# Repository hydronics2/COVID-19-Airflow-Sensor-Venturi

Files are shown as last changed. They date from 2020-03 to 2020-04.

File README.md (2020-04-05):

#### This sensor was abandoned because it was similar enough to another prototype using venturi type sensor based on a delta pressure reading. An ongoing airflow sensor project is here: [AFH55M12](https://github.com/hydronics2/COVID-19-Airflow-Sensor-AFH55M12) 

# Easy Flow Rate Sensor - venturi PCB

## Project Description ([from Helpful Engineering](https://www.helpfulengineering.org/))
The intent here is to create a monitoring device, based on a mass airflow meter, that can be used when splitting a ventilator into two or more patients. This will allow staff to monitor individual patients while being controlled by one device in extreme situations where the number of ventilators are not enough to handle the number of patients. The readout should be visible locally on the device and there may need to be parameters input by staff to create a safe operating range and to possibly create alarms when the system is measuring an out of range parameter.

### [Project Requirements](https://docs.google.com/document/d/17Ps910A2vRwnM4EM6F-71GNG1XNa0PaeImd53F7428c/edit?usp=sharing)

This version of the flow rate sensor PCB has off the shelf micro-controllers for quick prototyping. Developed through

The printed circuit board (PCB) accepts multiple Arduino platforms made by Adafruit including their line of [Adafruit Feather](https://www.adafruit.com/category/777) type micro-controllers and [Adafruit ItsyBitsy](https://www.adafruit.com/category/1008) micro-controllers.   The Adafruit feathers include wifi and SAMD M0 and M4 options. All the ItsyBitsy 3V models (M0, M4, and 32u4) should work fine.

[google Doc](https://docs.google.com/document/d/14zgp7OhsyWClFdLCb04ITVAHAoAawH8Gl29P4oe5PJs/edit?usp=sharing)

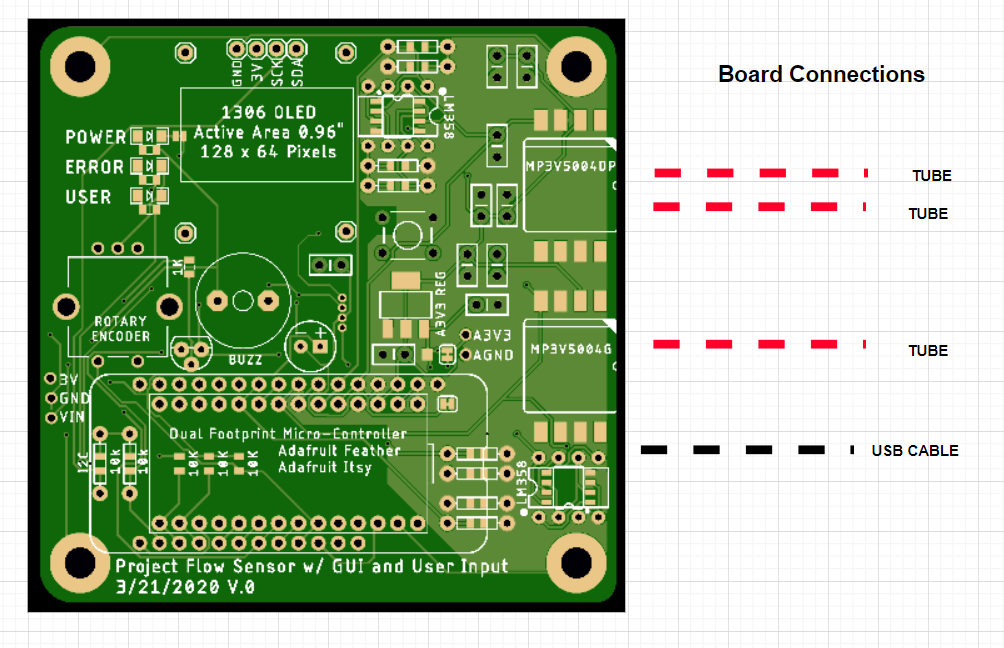
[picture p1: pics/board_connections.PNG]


### Still to do
- select the operational amplifiers and gain serving the pressure sensors
- Select alarm conditions
- Might need to add a separate power connector (⅛” barrel?)  as the USB micro connector might not be strong enough
- Verify any i2C conflicts between humidity sensor and OLED display

### General Operation
.....

### Bill of Materials
- differential pressure sensor, MP3V5004DP,
- gauge pressure sensor, MP3V5004G
- humidity sensor through-hole - H1H800, digikey 480-5706-1-ND
- humidity sensor surface mount - SHTC3, digikey 1649-1100-1-ND
- piezo buzzer, generic, 6.5mm pitch
- transistor to drive piezo pn2222A
- oled display, generic 1306 OLED, 128 x 64 pixels
- Linear 3.3v regulator LDL1117S33R
- Rotary Encoder and momentary switch, Bourns PEC12R-4220F-S0012-ND
- generic 6mm user defined momentary tactile switch
- generic 1206 smd LEDs for Power, Error, and TBD LED indicator

### Pressure Sensors
Two pressure sensors used here. Both manufactured by [NXP MP3V5004 Series](https://www.nxp.com/docs/en/data-sheet/MP3V5004G.pdf)
- One pressure sensor measures differential pressure from an external venturi
- One pressure sensor measures gauge pressure.
Both pressure sensors are connected directly to the micro-controllers ADC inputs as well as operational amplifiers so their outputs may be amplified as needed. (A0, A1, A2, A3,A4,A5).
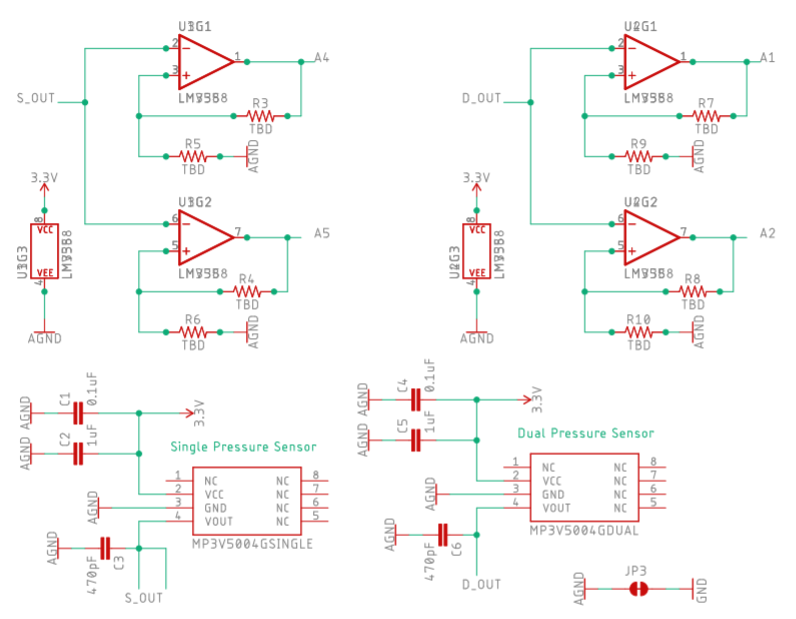
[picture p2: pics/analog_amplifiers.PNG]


### Micro-Controller Pinout
#### Feather ESP32 Pinout
#### Not up to date
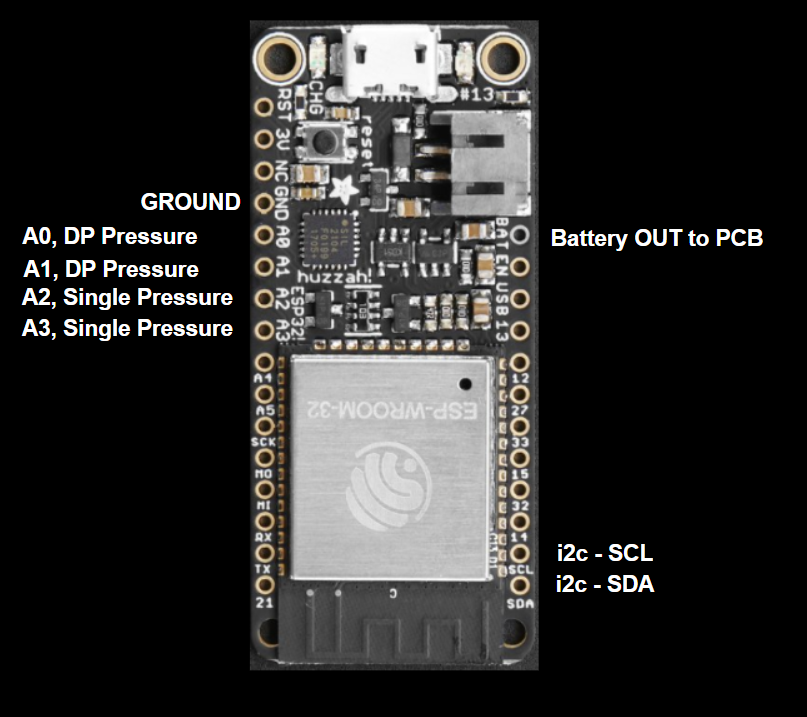
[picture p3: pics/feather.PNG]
feather

#### ItsyBitsy Pinout
#### Not up to date
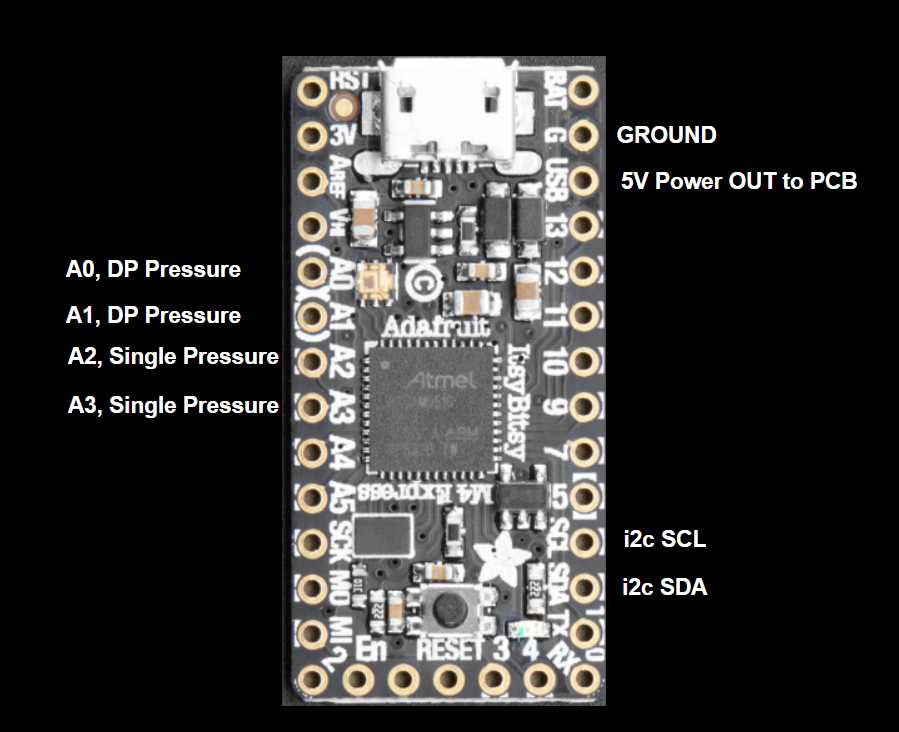
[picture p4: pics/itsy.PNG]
itsy


### Power
Power is delivered through the USB cable on the micro-controller. The Feather micro-controllers have a lipo charge circuit.  The main board is powered from the vBat pin of the micro-controller. The smaller Adafruit micro-controller does not have a lipo charge circuit and powers the PCB from the USB pin.
Feather lipo charge circuit. A 3.3v linear regulator is the analog power supply to the pressure sensors and operational amplifiers. This is a generic 3.3V regulator: LDL1117S33R
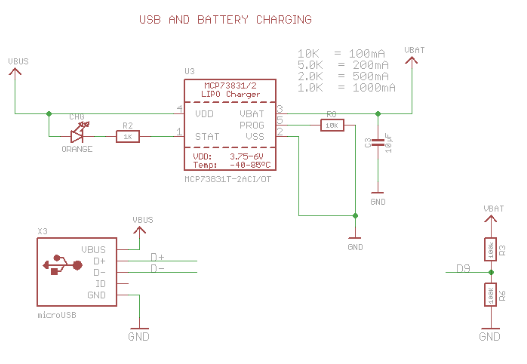
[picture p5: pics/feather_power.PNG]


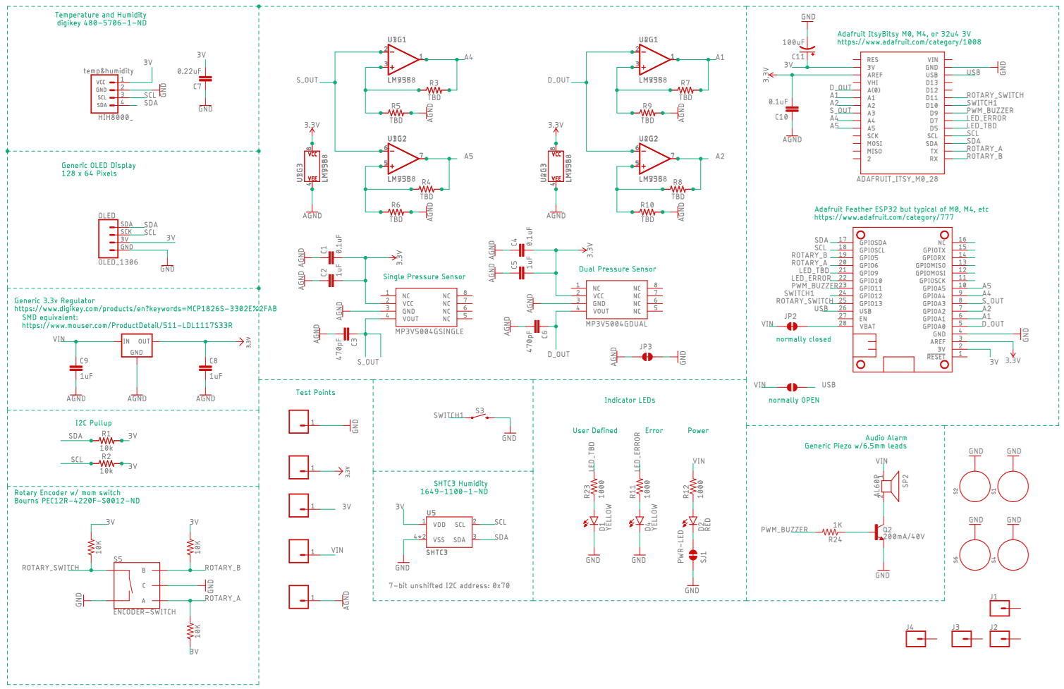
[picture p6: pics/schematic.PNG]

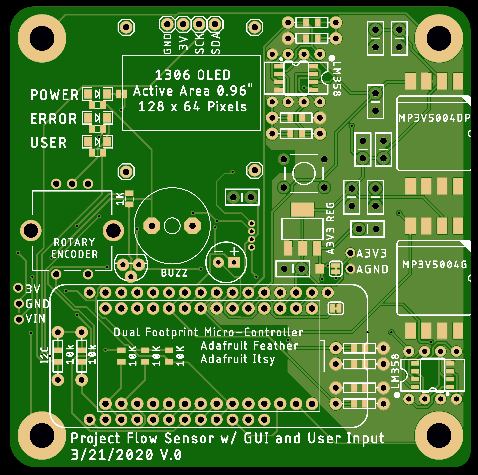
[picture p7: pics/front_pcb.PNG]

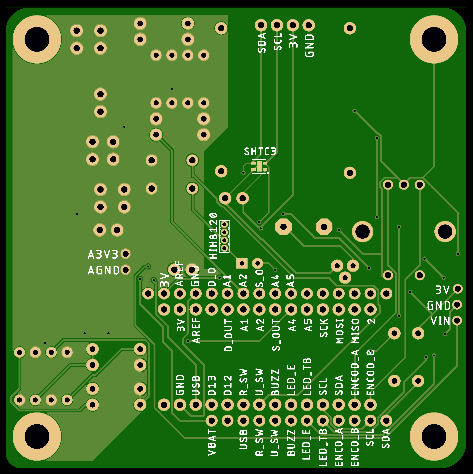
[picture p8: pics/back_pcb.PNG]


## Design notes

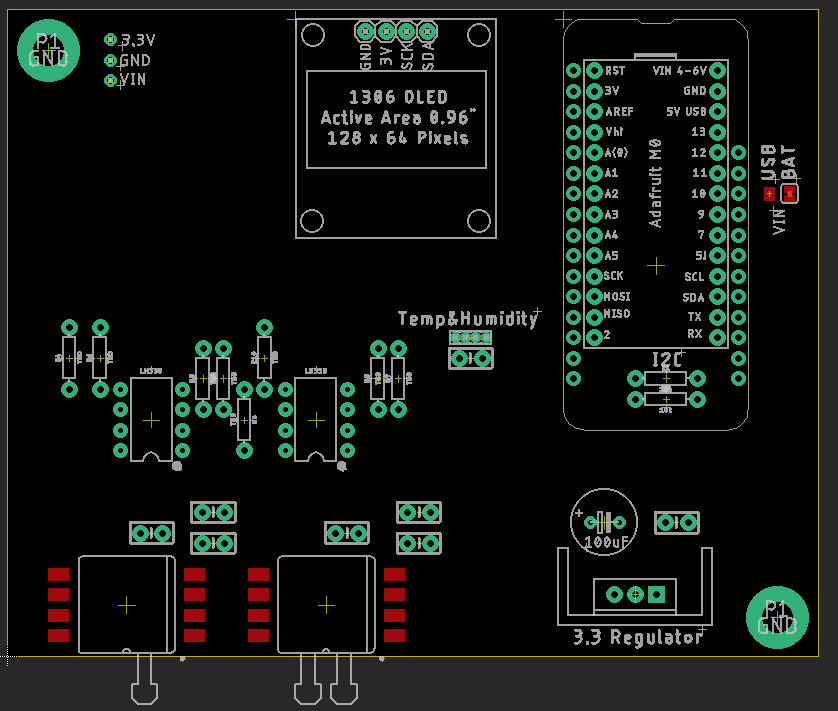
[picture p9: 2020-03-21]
pics/board view.PNG

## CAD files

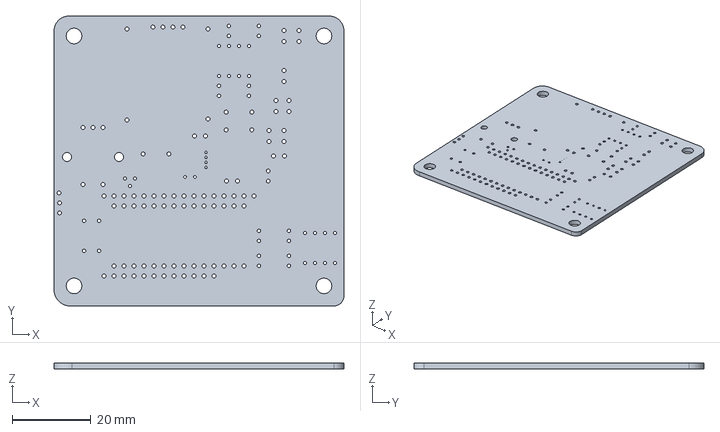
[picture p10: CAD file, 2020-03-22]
PCB files/kicad/air_flow.step
73.7 x 73.7 x 1.60 mm

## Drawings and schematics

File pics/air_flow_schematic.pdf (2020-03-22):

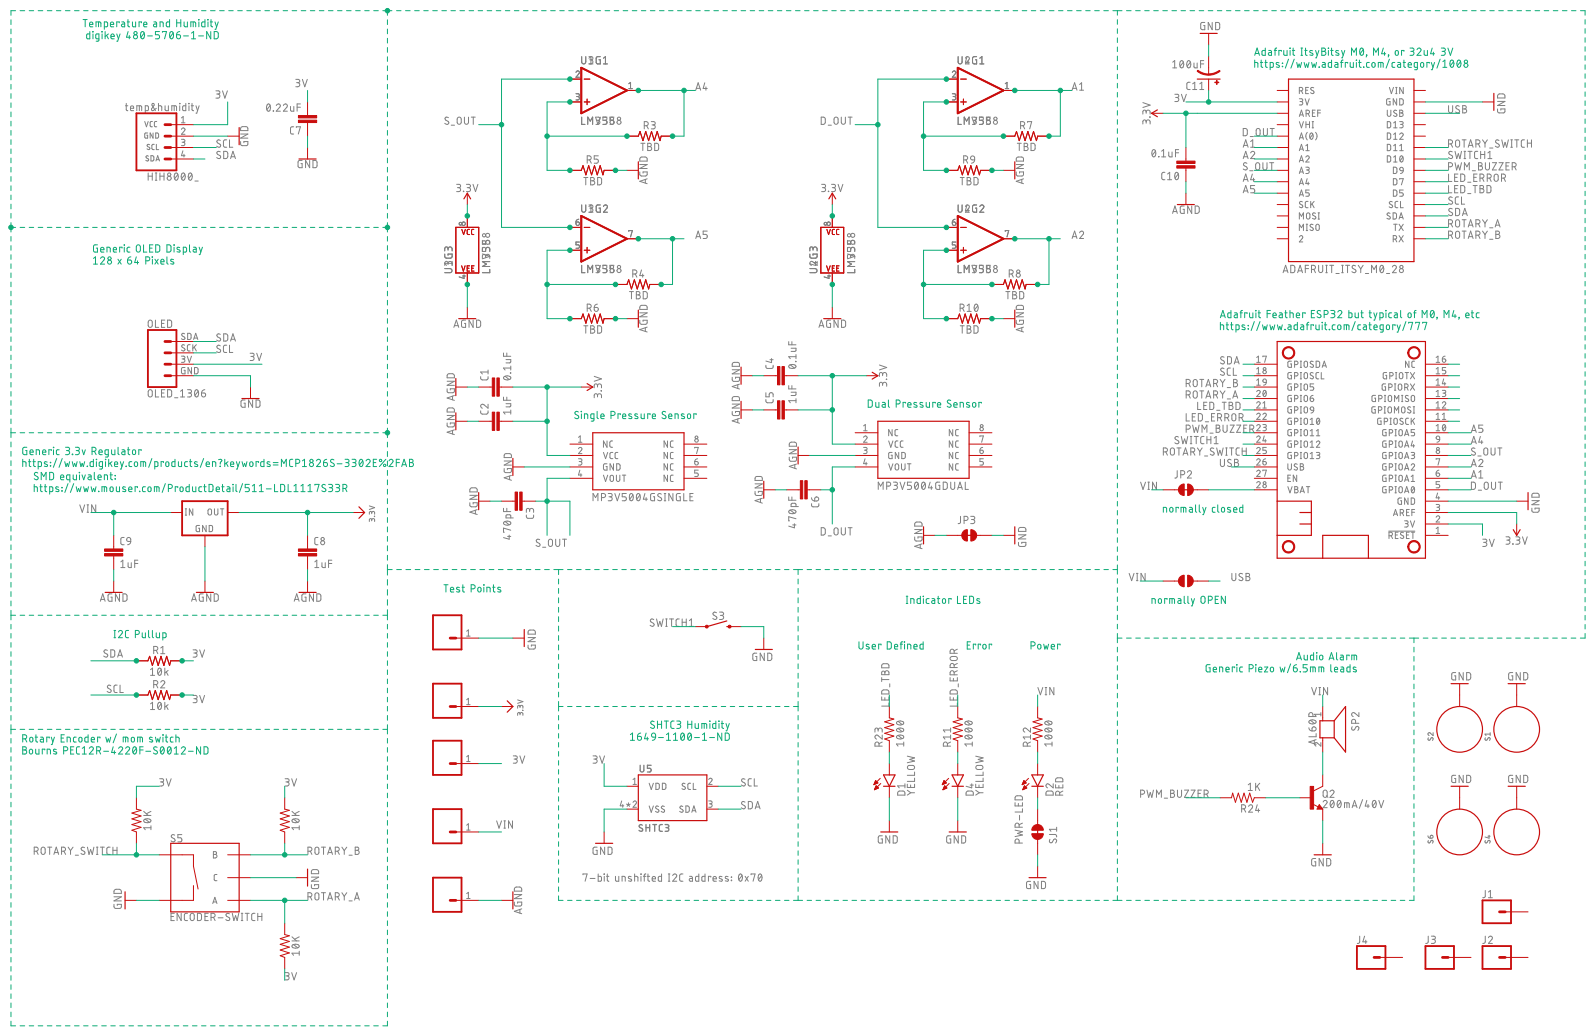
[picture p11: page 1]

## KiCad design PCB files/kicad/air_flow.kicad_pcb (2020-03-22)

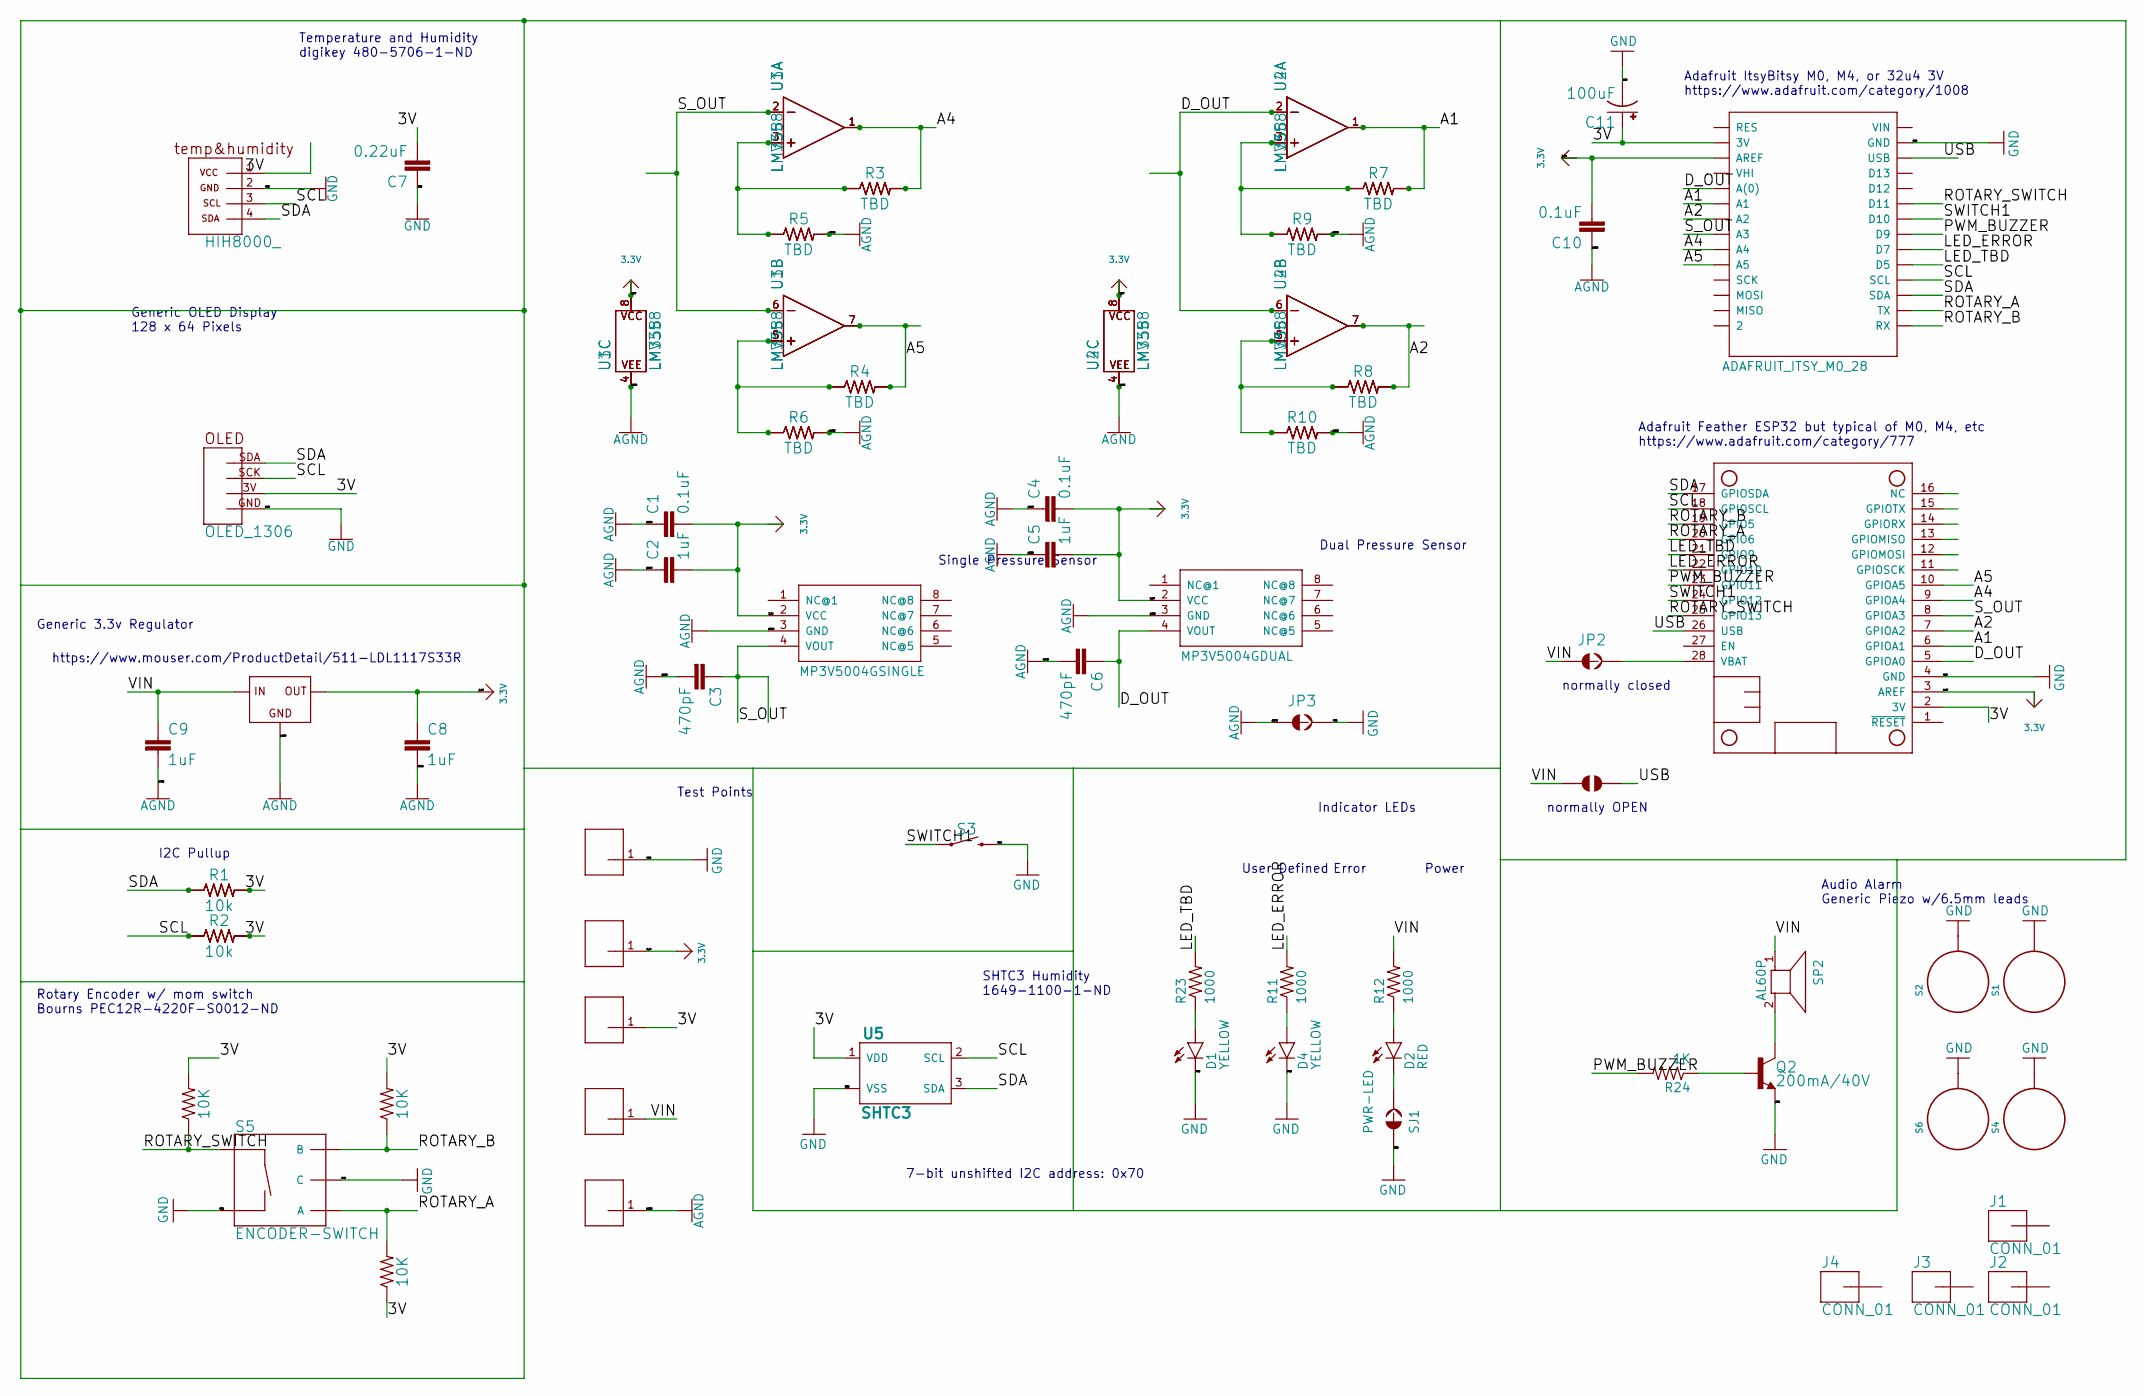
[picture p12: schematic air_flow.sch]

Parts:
3V_REGULATOR1: LDL1117_5V_REG; SOT223
C1, C4, C10: 0.1uF; CAP-PTH-SMALL-KIT
C2, C5, C8, C9: 1uF; CAP-PTH-SMALL-KIT
C3, C6: 470pF; CAP-PTH-SMALL-KIT
C7: 0.22uF; CAP-PTH-SMALL-KIT
C11: 100uF; CPOL-RADIAL-2.5MM-6.5MM
D1, D4: YELLOW; LED-1206
D2: RED; LED-1206
J1, J2, J3, J4: CONN_01; 1X01
JP1: JUMPER-SMT_2_NO_NO-SILK; SMT-JUMPER_2_NO_NO-SILK
JP2, JP3: JUMPER-SMT_2_NC_TRACE_SILK; SMT-JUMPER_2_NC_TRACE_SILK
MS2: FEATHERWING_NODIM; FEATHERWING_DIM
Q2: 200mA/40V; TO-92
R1, R2: 10k; AXIAL-0.3
R3, R4, R5, R6, R7, R8, R9, R10: TBD; AXIAL-0.3
R11, R12, R23: 1000; 0805
R13, R14, R15, R16, R17, R18, R19, R20, R21, R22: 0.3; 0805
R24: 1K; 0805
R26, R27, R28: 10K; 0805
S1, S2, S4, S6: STANDOFF_ELECTRICAL5-32; STANDOFF_ELECTRICAL_5_32
S3: MOMENTARY-SWITCH-SPST-PTH-6.0MM-KIT; TACTILE_SWITCH_PTH_6.0MM_KIT
S5: ENCODER-SWITCH; ROTARY_ENC_PLAIN
SJ1: PWR-LED; PAD-JUMPER-2-NC_BY_TRACE_NO_SILK
SP2: AL60P
U1, U2: LM358; DIP08
U3, U4: LMV358; SO08
U5: SHTC3
U$1: OLED_1306
U$2: MP3V5004GSINGLE; MP3V5004GP
U$3: MP3V5004GDUAL; MP3V5004DP
U$4: HIH8000_; HIH8120_TH
U$20, U$26, U$31, U$39, U$40: CONN_0138MILL; 1X01-40MILL
U$45: ADAFRUIT_ITSY_M0_28; ADAFRUIT_ITS_MO_28

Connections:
3.3V: 3V_REGULATOR1.2 (OUT), 3V_REGULATOR1.4 (OUT), C1.2, C2.2, C4.2, C5.2, C8.1, C10.2, MS2.3 (AREF), U1.8 (P$V+), U2.8 (P$V+), U3.8 (P$V+), U4.8 (P$V+), U$2.2 (VCC), U$3.2 (VCC), U$39.1, U$45.AREF
/3V: C7.2, C11.1 (+), MS2.2 (3V), R1.P$2 (2), R2.P$2 (2), R21.2, R22.2, R26.2, R27.1, R28.2, U5.1 (VDD), U$1.3V (VCC), U$4.1 (VCC), U$20.1, U$45.3V
/A1: MS2.6 (GPIOA1), R7.P$2 (2), R17.2, U2.1 (OUT), U4.1 (OUT), U$45.A1
/A2: MS2.7 (GPIOA2), R8.P$2 (2), R19.2, U2.7 (OUT), U4.7 (OUT), U$45.A2
/A4: MS2.9 (GPIOA4), R3.P$2 (2), R16.2, U1.1 (OUT), U3.1 (OUT), U$45.A4
/A5: MS2.10 (GPIOA5), R4.P$2 (2), R14.2, U1.7 (OUT), U3.7 (OUT), U$45.A5
/D_OUT: C6.1, MS2.5 (GPIOA0), U2.2 (-IN), U2.6 (-IN), U4.2 (-IN), U4.6 (-IN), U$3.4 (VOUT), U$45.A0 (A(0))
/LED_ERROR: MS2.22 (GPIO10), R11.2, U$45.D7
/LED_TBD: MS2.21 (GPIO9), R23.2, U$45.D5
/PWM_BUZZER: MS2.23 (GPIO11), R24.2, U$45.D9
/ROTARY_A: MS2.20 (GPIO6), R27.2, S5.A, U$45.TX
/ROTARY_B: MS2.19 (GPIO5), R26.1, S5.B, U$45.RX
/ROTARY_SWITCH: MS2.25 (GPIO13), R28.1, S5.SW+, U$45.D11
/SCL: MS2.18 (GPIOSCL), R2.P$1 (1), R22.1, U5.2 (SCL), U$1.SCK, U$4.3 (SCL), U$45.SCL
/SDA: MS2.17 (GPIOSDA), R1.P$1 (1), R21.1, U5.3 (SDA), U$1.SDA, U$4.4 (SDA), U$45.SDA
/SWITCH1: MS2.24 (GPIO12), S3.1, U$45.D10
/S_OUT: C3.1, MS2.8 (GPIOA3), U1.2 (-IN), U1.6 (-IN), U3.2 (-IN), U3.6 (-IN), U$2.4 (VOUT), U$45.A3
/USB: JP1.2, MS2.26 (USB), U$45.USB
/VIN: 3V_REGULATOR1.3 (IN), C9.1, JP1.1, JP2.1, R12.2, SP2.1, U$40.1
AGND: 3V_REGULATOR1.1 (GND), C1.1, C2.1, C3.2, C4.1, C5.1, C6.2, C8.2, C9.2, C10.1, JP3.1, R5.P$2 (2), R6.P$2 (2), R9.P$2 (2), R10.P$2 (2), R13.2, R15.2, R18.2, R20.2, U1.4 (P$V-), U2.4 (P$V-), U3.4 (P$V-), U4.4 (P$V-), U$2.3 (GND), U$3.3 (GND), U$26.1
GND: C7.1, C11.2 (-), D1.C, D4.C, JP3.2, MS2.4 (GND), Q2.1 (E), S1.P1, S2.P1, S3.3 (2), S4.P1, S5.C, S5.SW-, S6.P1, SJ1.1, U5.4 (VSS), U5.5 (VSS), U$1.GND, U$4.2 (GND), U$31.1, U$45.GND
unnamed: D1.A, R23.1
unnamed: D2.A, R12.1
unnamed: D2.C, SJ1.2
unnamed: D4.A, R11.1
unnamed: JP2.2, MS2.28 (VBAT)
unnamed: Q2.2 (B), R24.1
unnamed: Q2.3 (C), SP2.2
unnamed: R8.P$1 (1), R10.P$1 (1), R19.1, R20.1, U2.5 (+IN), U4.5 (+IN)
unnamed: R3.P$1 (1), R5.P$1 (1), R13.1, R16.1, U1.3 (+IN), U3.3 (+IN)
unnamed: R4.P$1 (1), R6.P$1 (1), R14.1, R15.1, U1.5 (+IN), U3.5 (+IN)
unnamed: R7.P$1 (1), R9.P$1 (1), R17.1, R18.1, U2.3 (+IN), U4.3 (+IN)

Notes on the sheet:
I2C Pullup
Dual Pressure Sensor
Single Pressure Sensor
Temperature and Humidity digikey 480-5706-1-ND
Generic OLED Display 128 x 64 Pixels
normally closed
normally OPEN
Adafruit ItsyBitsy M0, M4, or 32u4 3V https://www.adafruit.com/category/1008
Adafruit Feather ESP32 but typical of M0, M4, etc https://www.adafruit.com/category/777
Generic 3.3v Regulator
Test Points
Indicator LEDs
Power
Error
User Defined
https://www.mouser.com/ProductDetail/511-LDL1117S33R
Audio Alarm Generic Piezo w/6.5mm leads
Rotary Encoder w/ mom switch Bourns PEC12R-4220F-S0012-ND
7-bit unshifted I2C address: 0x70
SHTC3 Humidity 1649-1100-1-ND

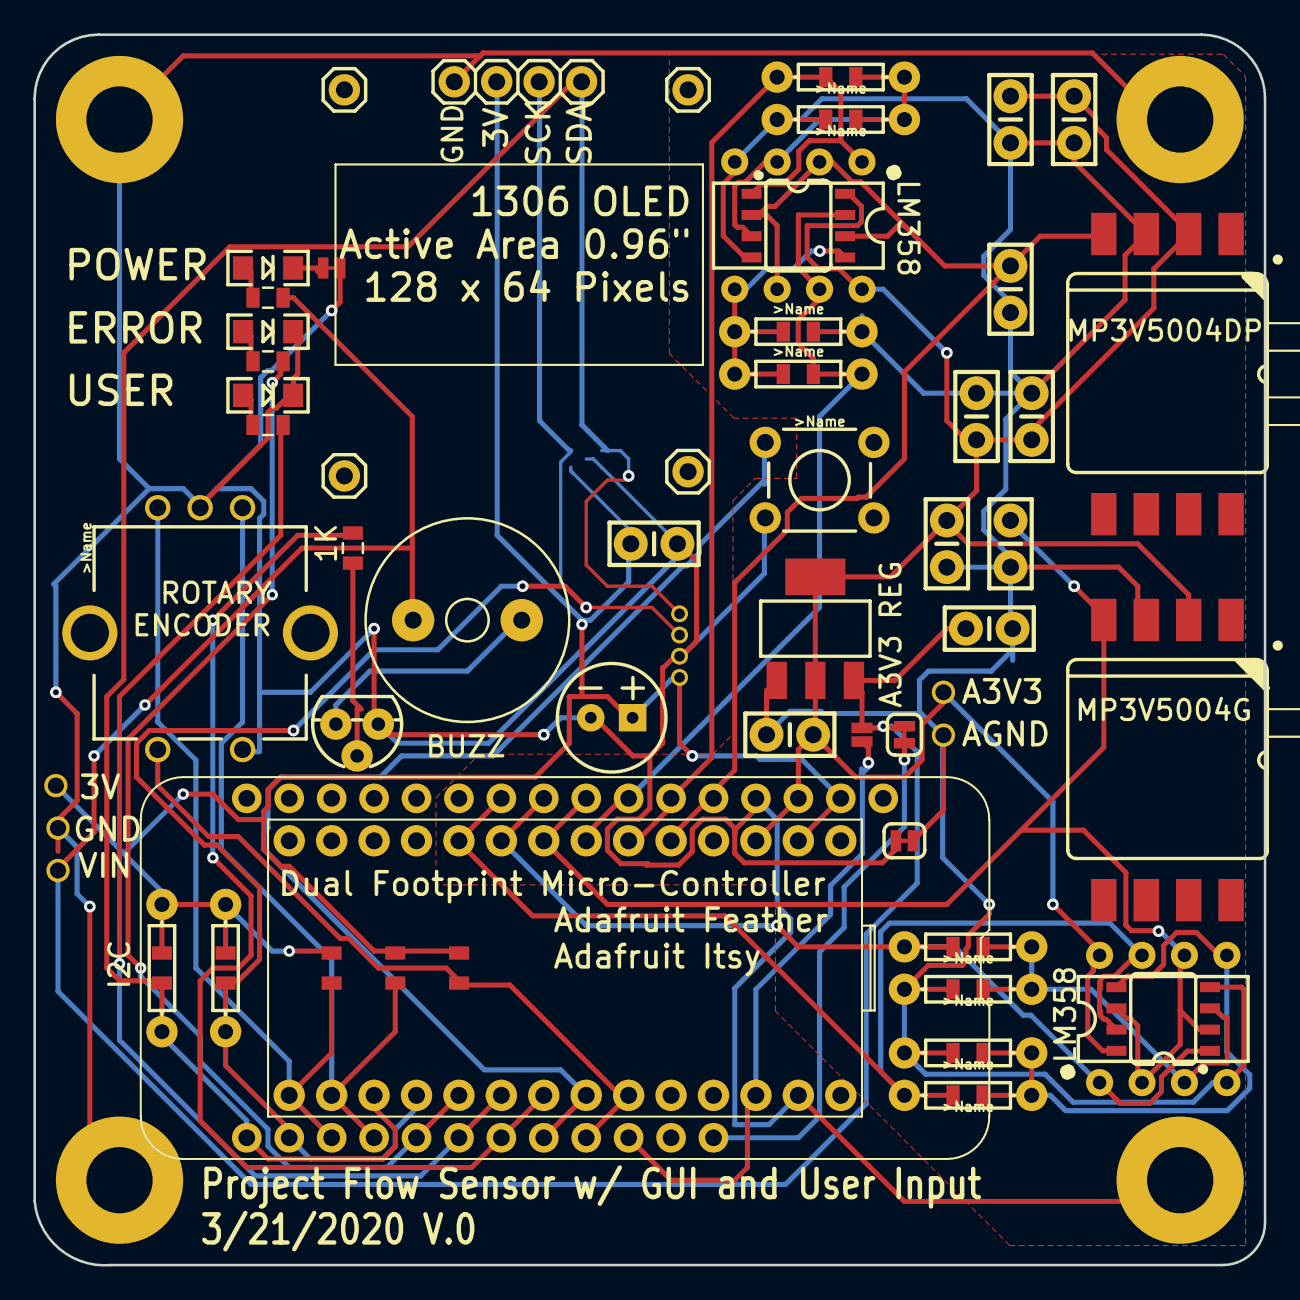
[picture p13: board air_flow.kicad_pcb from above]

Board: 2 copper layers, 73.7 x 73.7 mm, 74 parts (0 on the bottom side), 32 nets.

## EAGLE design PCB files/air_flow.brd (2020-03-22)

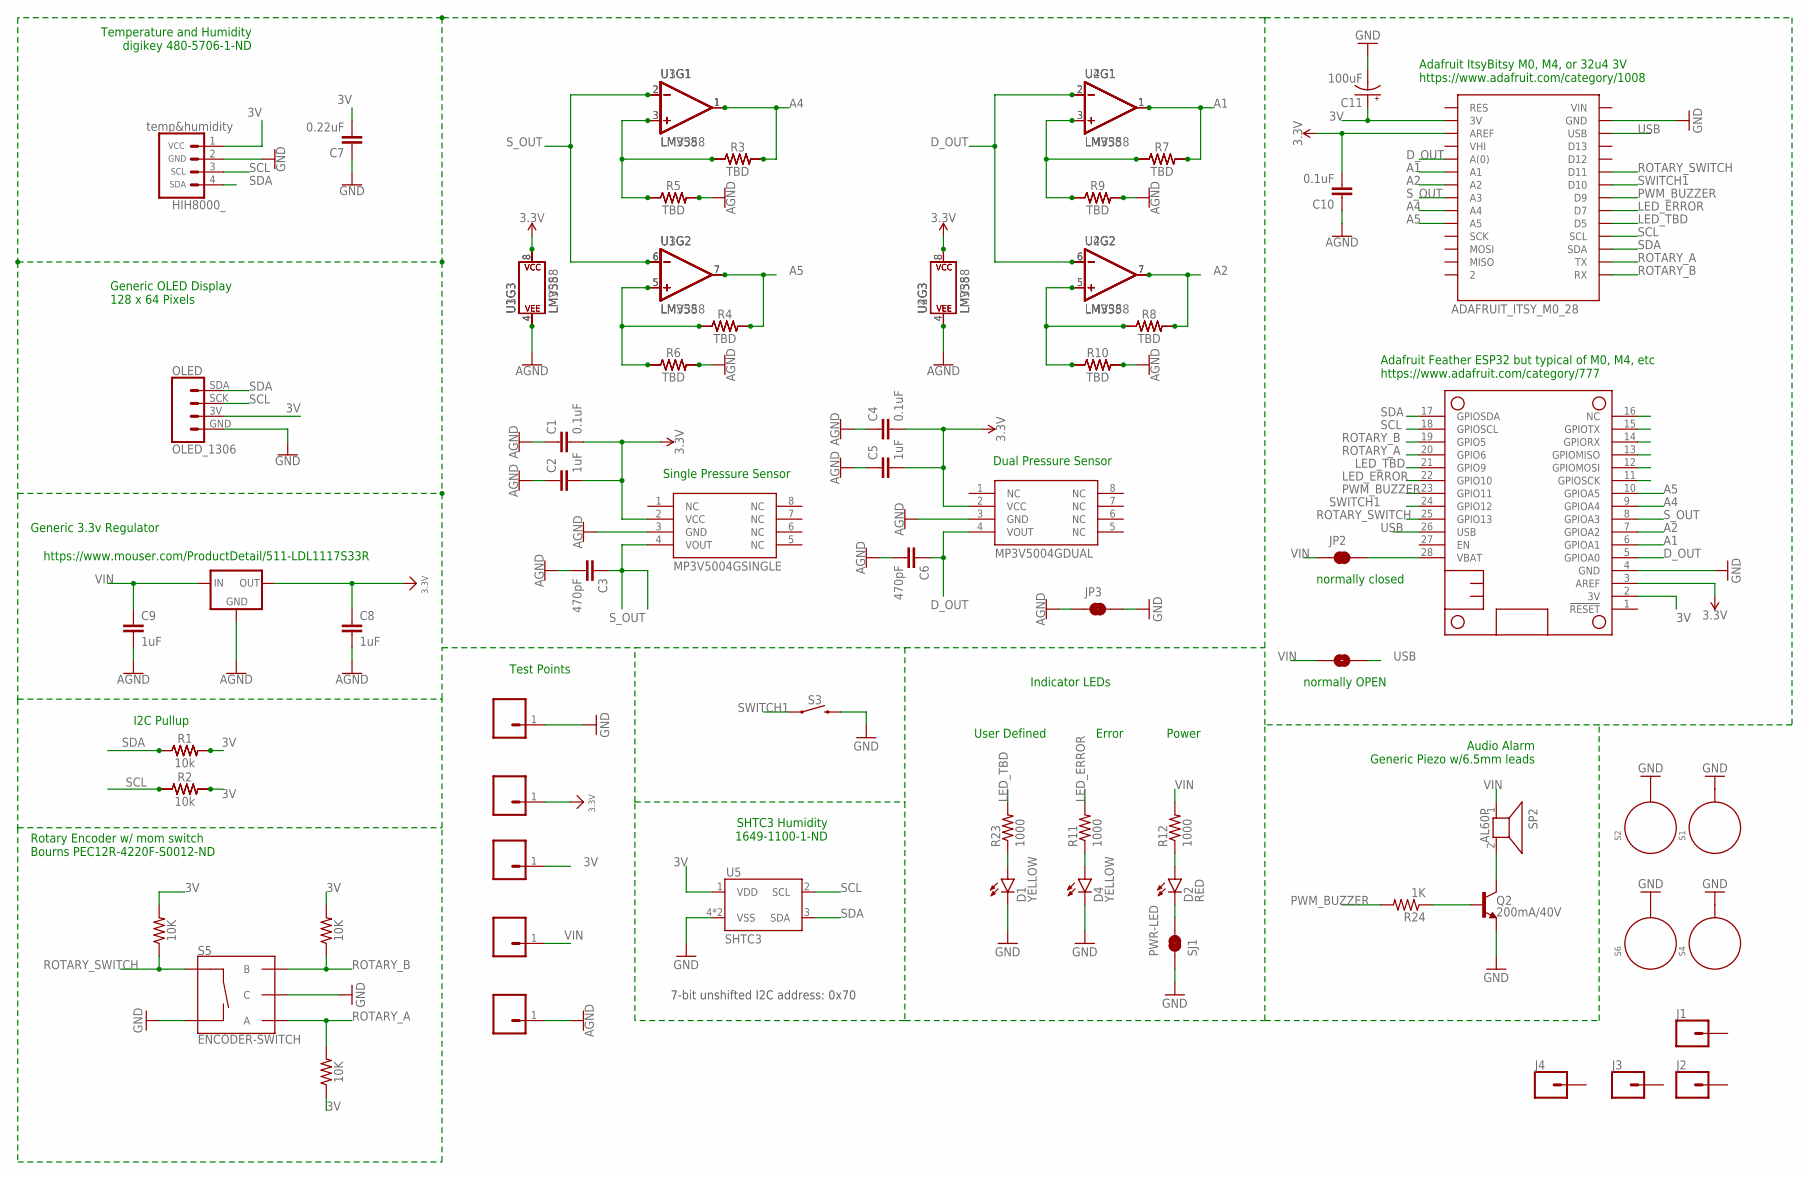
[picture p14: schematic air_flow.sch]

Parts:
3V_REGULATOR: LDL1117_5V_REG; SOT223
C1, C4, C10: 0.1uF; CAP-PTH-SMALL-KIT
C2, C5, C8, C9: 1uF; CAP-PTH-SMALL-KIT
C3, C6: 470pF; CAP-PTH-SMALL-KIT
C7: 0.22uF; CAP-PTH-SMALL-KIT
C11: 100uF; CPOL-RADIAL-2.5MM-6.5MM
D1, D4: YELLOW; LED-1206
D2: RED; LED-1206
J1, J2, J3, J4: CONN_01; 1X01
JP1: JUMPER-SMT_2_NO_NO-SILK; SMT-JUMPER_2_NO_NO-SILK
JP2, JP3: JUMPER-SMT_2_NC_TRACE_SILK; SMT-JUMPER_2_NC_TRACE_SILK
MS2: FEATHERWING_NODIM; FEATHERWING_DIM
Q2: 200mA/40V; TO-92
R1, R2: 10k; AXIAL-0.3
R3, R4, R5, R6, R7, R8, R9, R10: TBD; AXIAL-0.3
R11, R12, R23: 1000; 0805
R13, R14, R15, R16, R17, R18, R19, R20, R21, R22: 0.3; 0805
R24: 1K; 0805
R26, R27, R28: 10K; 0805
S1, S2, S4, S6: STANDOFF_ELECTRICAL5-32; STANDOFF_ELECTRICAL_5_32
S3: MOMENTARY-SWITCH-SPST-PTH-6.0MM-KIT; TACTILE_SWITCH_PTH_6.0MM_KIT
S5: ENCODER-SWITCH; ROTARY_ENC_PLAIN
SJ1: PWR-LED; PAD-JUMPER-2-NC_BY_TRACE_NO_SILK
SP2: AL60P
U1, U2: LM358; DIP08
U3, U4: LMV358; SO08
U5: SHTC3
U$1: OLED_1306
U$2: MP3V5004GSINGLE; MP3V5004GP
U$3: MP3V5004GDUAL; MP3V5004DP
U$4: HIH8000_; HIH8120_TH
U$20, U$26, U$31, U$39, U$40: CONN_0138MILL; 1X01-40MILL
U$45: ADAFRUIT_ITSY_M0_28; ADAFRUIT_ITS_MO_28

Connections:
3.3V: 3V_REGULATOR.2 (OUT), 3V_REGULATOR.4 (OUT), C1.2, C2.2, C4.2, C5.2, C8.1, C10.2, MS2.3 (AREF), U1.8 (P$V+), U2.8 (P$V+), U3.8 (P$V+), U4.8 (P$V+), U$2.2 (VCC), U$3.2 (VCC), U$39.1, U$45.AREF
3V: C7.2, C11.1 (+), MS2.2 (3V), R1.P$2 (2), R2.P$2 (2), R21.2, R22.2, R26.2, R27.1, R28.2, U5.1 (VDD), U$1.3V (VCC), U$4.1 (VCC), U$20.1, U$45.3V
A1: MS2.6 (GPIOA1), R7.P$2 (2), R17.2, U2.1 (OUT), U4.1 (OUT), U$45.A1
A2: MS2.7 (GPIOA2), R8.P$2 (2), R19.2, U2.7 (OUT), U4.7 (OUT), U$45.A2
A4: MS2.9 (GPIOA4), R3.P$2 (2), R16.2, U1.1 (OUT), U3.1 (OUT), U$45.A4
A5: MS2.10 (GPIOA5), R4.P$2 (2), R14.2, U1.7 (OUT), U3.7 (OUT), U$45.A5
AGND: 3V_REGULATOR.1 (GND), C1.1, C2.1, C3.2, C4.1, C5.1, C6.2, C8.2, C9.2, C10.1, JP3.1, R5.P$2 (2), R6.P$2 (2), R9.P$2 (2), R10.P$2 (2), R13.2, R15.2, R18.2, R20.2, U1.4 (P$V-), U2.4 (P$V-), U3.4 (P$V-), U4.4 (P$V-), U$2.3 (GND), U$3.3 (GND), U$26.1
D_OUT: C6.1, MS2.5 (GPIOA0), U2.2 (-IN), U2.6 (-IN), U4.2 (-IN), U4.6 (-IN), U$3.4 (VOUT), U$45.A0 (A(0))
GND: C7.1, C11.2 (-), D1.C, D4.C, JP3.2, MS2.4 (GND), Q2.1 (E), S1.P1, S2.P1, S3.3 (2), S4.P1, S5.C, S5.SW-, S6.P1, SJ1.1, U5.4 (VSS), U5.5 (VSS), U$1.GND, U$4.2 (GND), U$31.1, U$45.GND
LED_ERROR: MS2.22 (GPIO10), R11.2, U$45.D7
LED_TBD: MS2.21 (GPIO9), R23.2, U$45.D5
unnamed: R3.P$1 (1), R5.P$1 (1), R13.1, R16.1, U1.3 (+IN), U3.3 (+IN)
unnamed: D2.A, R12.1
unnamed: D1.A, R23.1
unnamed: R4.P$1 (1), R6.P$1 (1), R14.1, R15.1, U1.5 (+IN), U3.5 (+IN)
unnamed: R7.P$1 (1), R9.P$1 (1), R17.1, R18.1, U2.3 (+IN), U4.3 (+IN)
unnamed: R8.P$1 (1), R10.P$1 (1), R19.1, R20.1, U2.5 (+IN), U4.5 (+IN)
unnamed: Q2.3 (C), SP2.2
unnamed: Q2.2 (B), R24.1
unnamed: D4.A, R11.1
unnamed: D2.C, SJ1.2
PWM_BUZZER: MS2.23 (GPIO11), R24.2, U$45.D9
ROTARY_A: MS2.20 (GPIO6), R27.2, S5.A, U$45.TX
ROTARY_B: MS2.19 (GPIO5), R26.1, S5.B, U$45.RX
ROTARY_SWITCH: MS2.25 (GPIO13), R28.1, S5.SW+, U$45.D11
SCL: MS2.18 (GPIOSCL), R2.P$1 (1), R22.1, U5.2 (SCL), U$1.SCK, U$4.3 (SCL), U$45.SCL
SDA: MS2.17 (GPIOSDA), R1.P$1 (1), R21.1, U5.3 (SDA), U$1.SDA, U$4.4 (SDA), U$45.SDA
SWITCH1: MS2.24 (GPIO12), S3.1, U$45.D10
S_OUT: C3.1, MS2.8 (GPIOA3), U1.2 (-IN), U1.6 (-IN), U3.2 (-IN), U3.6 (-IN), U$2.4 (VOUT), U$45.A3
USB: JP1.2, MS2.26 (USB), U$45.USB
VBAT: JP2.2, MS2.28 (VBAT)
VIN: 3V_REGULATOR.3 (IN), C9.1, JP1.1, JP2.1, R12.2, SP2.1, U$40.1

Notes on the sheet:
I2C Pullup
Dual Pressure Sensor
Single Pressure Sensor
Temperature and Humidity digikey 480-5706-1-ND
Generic OLED Display 128 x 64 Pixels
normally closed
normally OPEN
Adafruit ItsyBitsy M0, M4, or 32u4 3V https://www.adafruit.com/category/1008
Adafruit Feather ESP32 but typical of M0, M4, etc https://www.adafruit.com/category/777
Generic 3.3v Regulator
Test Points
Indicator LEDs
Power
Error
User Defined
https://www.mouser.com/ProductDetail/511-LDL1117S33R
Audio Alarm Generic Piezo w/6.5mm leads
Rotary Encoder w/ mom switch Bourns PEC12R-4220F-S0012-ND
7-bit unshifted I2C address: 0x70
SHTC3 Humidity 1649-1100-1-ND

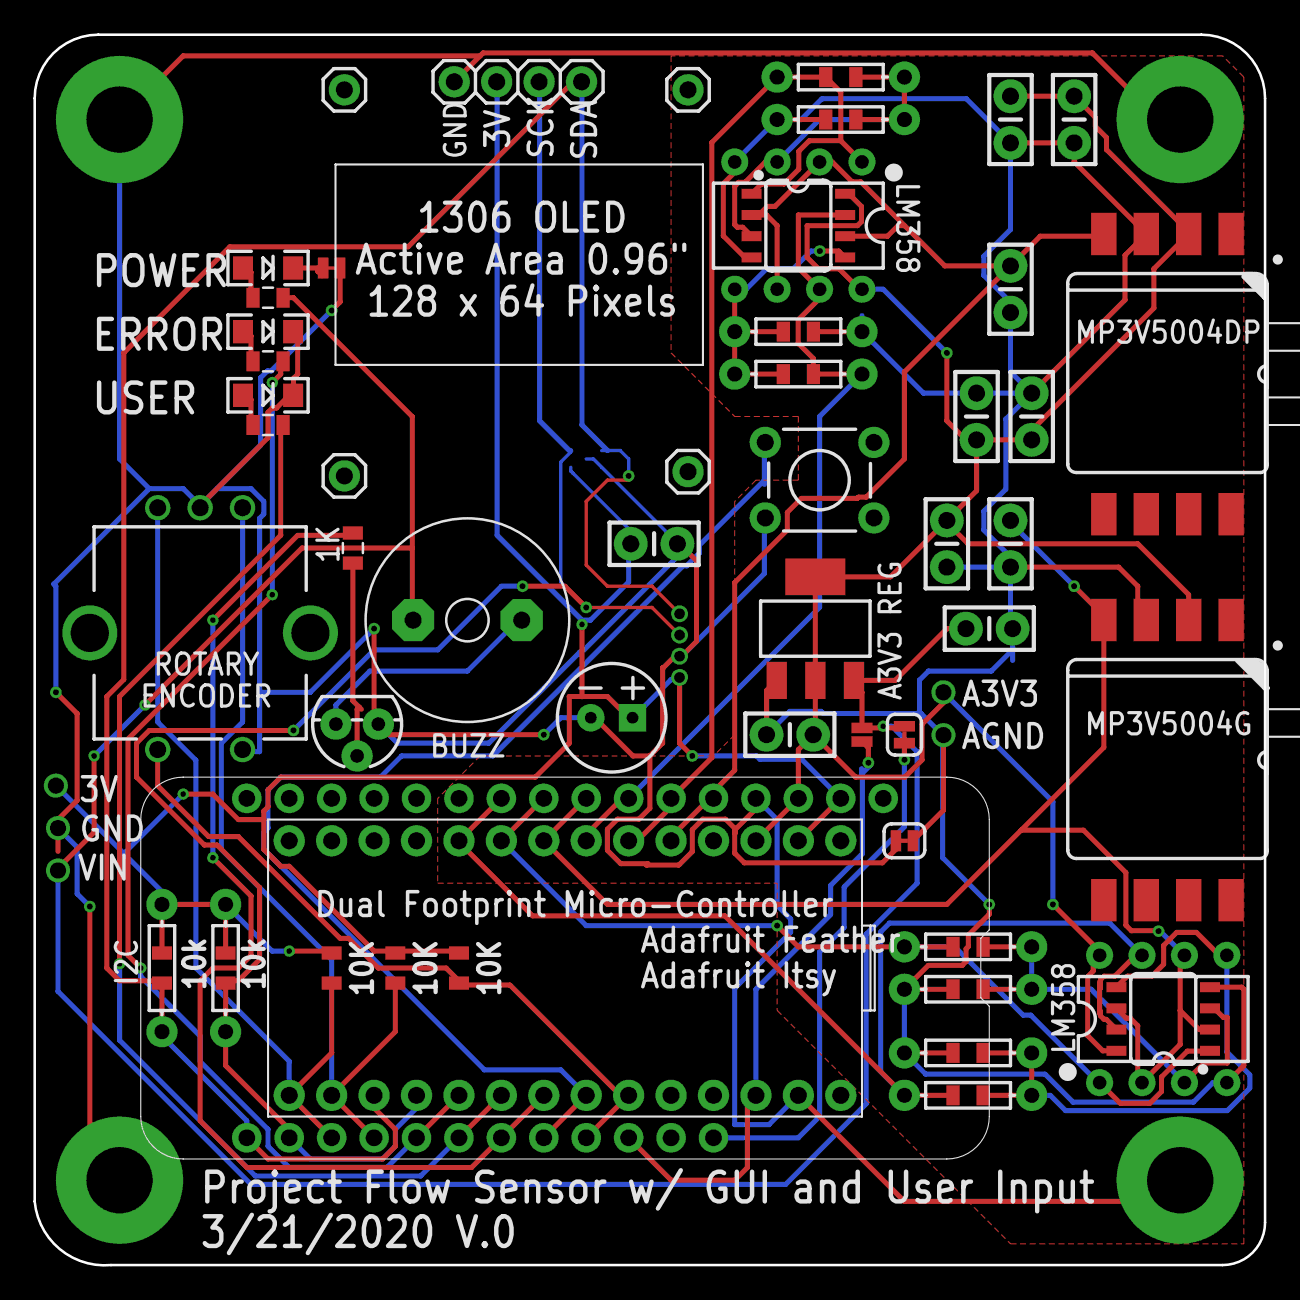
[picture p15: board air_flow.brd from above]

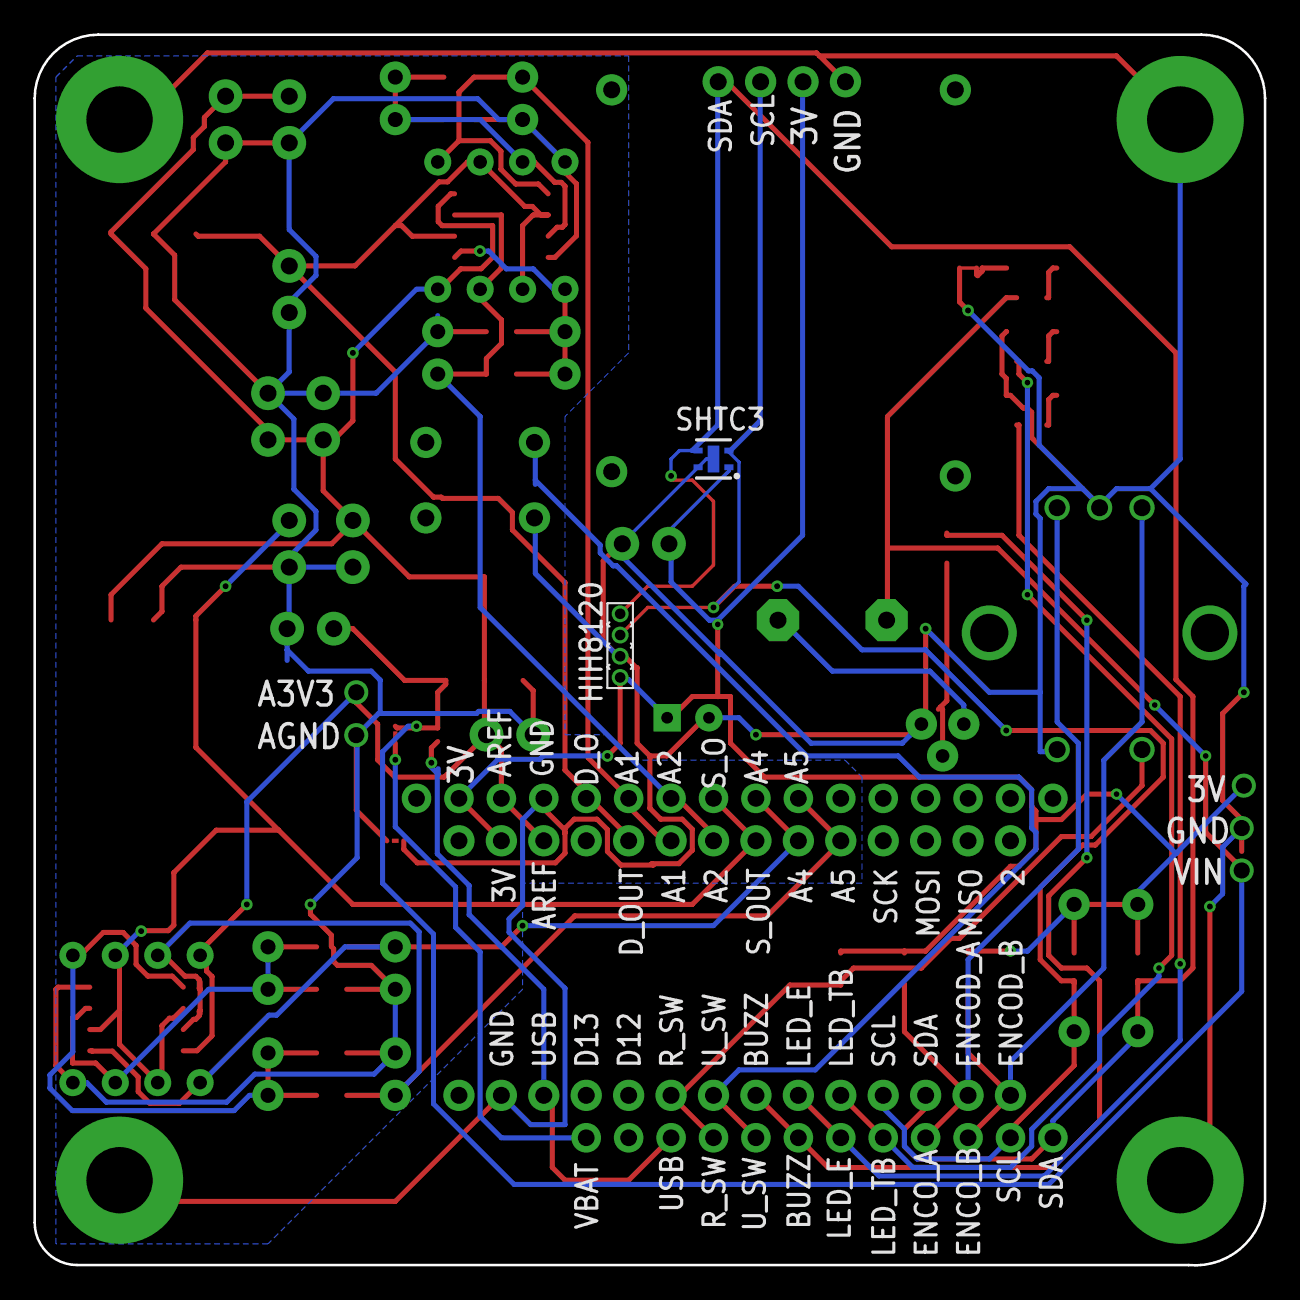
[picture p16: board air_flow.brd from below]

Board: 2 copper layers, 73.7 x 73.7 mm, 74 parts (2 on the bottom side), 32 nets.

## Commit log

2020-03-21 eagle files
    [air_flow.brd, air_flow.sch]
2020-03-22 updated ealge v0 to JLCPCB
    [air_flow.brd, air_flow.sch]
2020-03-22 added kicad step file
    [air_flow.brd, air_flow.kicad_pcb, air_flow.step]

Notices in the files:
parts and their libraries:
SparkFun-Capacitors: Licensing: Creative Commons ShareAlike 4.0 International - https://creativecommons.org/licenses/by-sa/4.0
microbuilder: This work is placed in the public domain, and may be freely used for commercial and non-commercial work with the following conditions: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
